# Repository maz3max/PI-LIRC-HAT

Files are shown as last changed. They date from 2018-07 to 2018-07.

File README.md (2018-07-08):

# Raspberry PI LIRC HAT #
## Now, you can control everything with an infrared remote with your Raspberry Pi! ##

This an extension PCB for Raspberry PIs with 40 Pins.

Its purpose is to provide a infrared interface compatible with [LIRC](http://www.lirc.org/).

I did my very best to fulfill the [Raspberry Pi HAT specification](https://github.com/raspberrypi/hats).

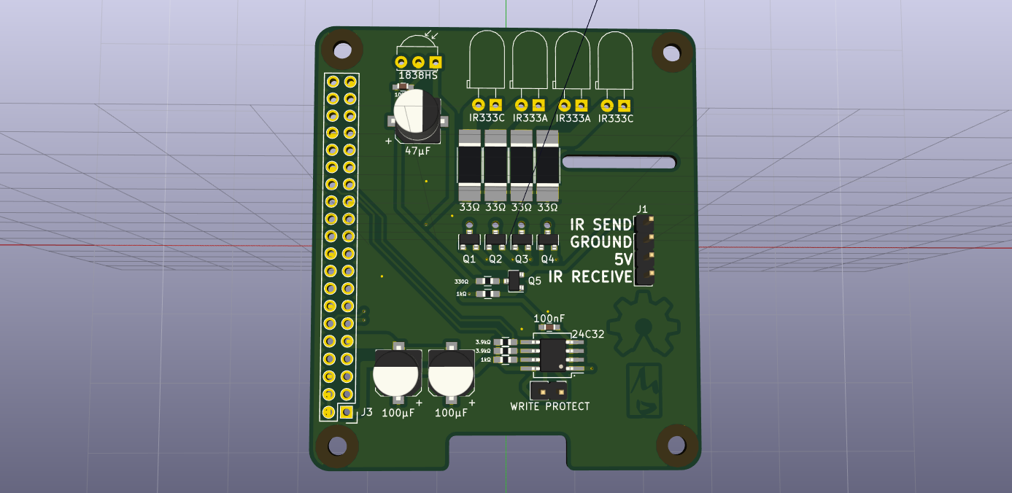
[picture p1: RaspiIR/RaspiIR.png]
3D render


To build it, you need:
* bravery, soldering skills, linux
* The PCB like in the design file in RaspiIR/RaspiIR.kicad_pcb
* 2x 100nF Ceramic Cap 0603 SMD
* 2x 100uF Electrolytic Cap SMD 6.3mm diameter
* 2x IR-LED: Everlight IR333-A
* 2x IR-LED: Everlight IR333C/H0/L10
* 1x TSOP383xx or AX-1838 IR receiver
* 5x MMBT3904TPMSCT-ND NPN transistor SOT-23
* 1x 24C32 I2C eeprom SOIC-8 or SO-8
* 4x 33R 1W 2512 SMD resistor
* 1x 330R 0603 SMD resistor
* 2x 1k 0603 SMD resistor
* 2x 3.9k 0603 SMD resistor
* 1x Pin-Header 0.1" pitch 2x20 pins (at least 8mm high)

After soldering it all together, you have to generate and write content on the ID eeprom. Its purpose is to load the driver when your Raspberry Pi boots.

To achieve this, follow these steps:

1. compile the tools in pi-lirc-hat/eepromutils with ```make```
2. use ```./eepmake eeprom_settings.txt lircHAT.eep lirc-rpi-overlay.dtbo -c setup-readme-blob``` to compile the eeprom content
3. connect the eeprom to the I2C-Pins of a Raspberry (NOT the ID-SCL, ID-SDA pins)
4. read on how to use eepflash with ```./eepflash.sh -h```
5. use eepflash to write the content to the ID eeprom, e.g.:```./eepflash.sh -w -f=lircHAT.eep -t=24c32 -d=1 -a=50```

After that, you have to install lirc on the Raspberry. This is documented in pi-lirc-hat/eepromutils/setup-readme-blob.

You can also find this in /proc/device-tree/hat/custom_0, because it is included in the eeprom! :D

The design with the 4 IR leds is inspired by [TV-B-Gone](https://learn.adafruit.com/tv-b-gone-kit/overview). The driver overlay is from the [Raspberry Pi Kernel source tree](https://github.com/raspberrypi/linux) with slight modifications. The PCB was designed using [KiCAD](http://kicad-pcb.org/). I used a template for the PCB design which can be found [here](https://github.com/xesscorp/RPi_Hat_Template)

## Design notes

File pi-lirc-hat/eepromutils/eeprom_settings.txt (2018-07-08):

########################################################################
# EEPROM settings text file
#
# Edit this file for your particular board and run through eepmake tool,
# then use eepflash tool to write to attached HAT ID EEPROM 
#
# Tools available:
#  eepmake   Parses EEPROM text file and creates binary .eep file
#  eepdump   Dumps a binary .eep file as human readable text (for debug)
#  eepflash  Write or read .eep binary image to/from HAT EEPROM
#
########################################################################

########################################################################
# Vendor info

# 128 bit UUID. If left at zero eepmake tool will auto-generate
# RFC 4122 compliant UUID
product_uuid 00000000-0000-0000-0000-000000000000

# 16 bit product id
product_id 0x1337

# 16 bit product version
product_ver 0x0001

# ASCII vendor string  (max 255 characters)
vendor "maz3max"

# ASCII product string (max 255 characters)
product "Raspberry LIRC HAT"

########################################################################
# GPIO bank settings, set to nonzero to change from the default.
# NOTE these setting can only be set per BANK, uncommenting any of
# these will force the bank to use the custom setting.

# drive strength, 0=default, 1-8=2,4,6,8,10,12,14,16mA, 9-15=reserved
gpio_drive 0

# 0=default, 1=slew rate limiting, 2=no slew limiting, 3=reserved
gpio_slew 0

# 0=default, 1=hysteresis disabled, 2=hysteresis enabled, 3=reserved
gpio_hysteresis 0

# If board back-powers Pi via 5V GPIO header pins:
# 0 = board does not back-power
# 1 = board back-powers and can supply the Pi with a minimum of 1.3A
# 2 = board back-powers and can supply the Pi with a minimum of 2A
# 3 = reserved
# If back_power=2 then USB high current mode will be automatically 
# enabled on the Pi
back_power 0

########################################################################
# GPIO pins, uncomment for GPIOs used on board
# Options for FUNCTION: INPUT, OUTPUT, ALT0-ALT5
# Options for PULL: DEFAULT, UP, DOWN, NONE
# NB GPIO0 and GPIO1 are reserved for ID EEPROM so cannot be set

#         GPIO  FUNCTION  PULL
#         ----  --------  ----
#setgpio  2     INPUT     DEFAULT
#setgpio  3     INPUT     DEFAULT
#setgpio  4     INPUT     DEFAULT
#setgpio  5     INPUT     DEFAULT
#setgpio  6     INPUT     DEFAULT
#setgpio  7     INPUT     DEFAULT
#setgpio  8     INPUT     DEFAULT
#setgpio  9     INPUT     DEFAULT
#setgpio  10    INPUT     DEFAULT
#setgpio  11    INPUT     DEFAULT
#setgpio  12    INPUT     DEFAULT
#setgpio  13    INPUT     DEFAULT
#setgpio  14    INPUT     DEFAULT
#setgpio  15    INPUT     DEFAULT
#setgpio  16    INPUT     DEFAULT
setgpio  17    OUTPUT    DEFAULT
setgpio  18    INPUT     DEFAULT
#setgpio  19    INPUT     DEFAULT
#setgpio  20    INPUT     DEFAULT
#setgpio  21    INPUT     DEFAULT
#setgpio  22    INPUT     DEFAULT
#setgpio  23    INPUT     DEFAULT
#setgpio  24    INPUT     DEFAULT
#setgpio  25    INPUT     DEFAULT
#setgpio  26    INPUT     DEFAULT
#setgpio  27    INPUT     DEFAULT

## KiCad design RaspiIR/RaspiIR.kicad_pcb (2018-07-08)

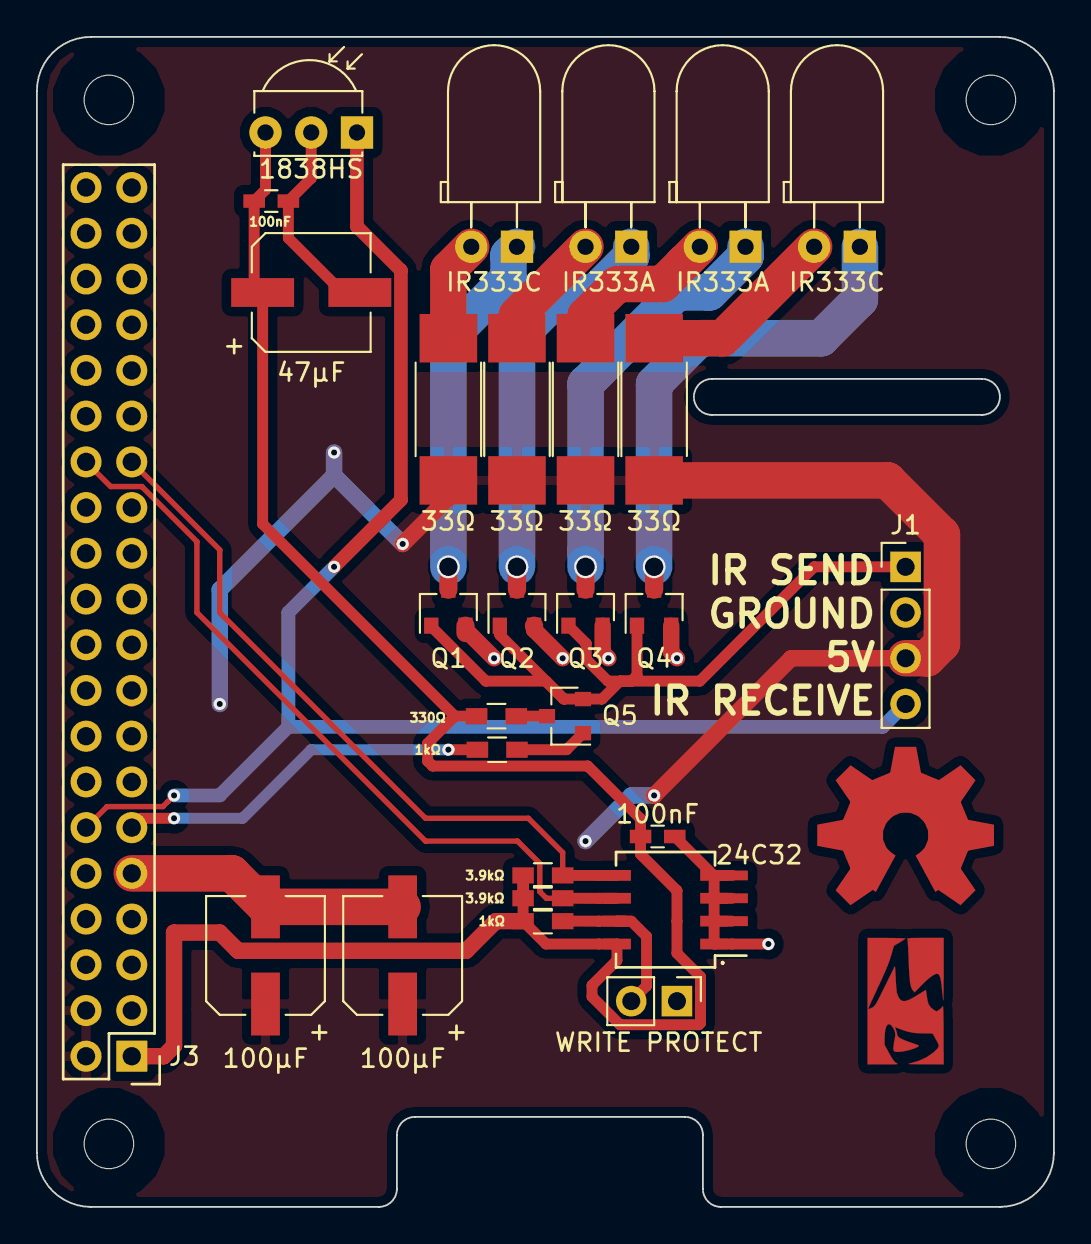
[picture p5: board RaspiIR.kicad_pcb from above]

Board: 2 copper layers, 56.5 x 65.0 mm, 30 parts (0 on the bottom side), 19 nets.

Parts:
1kΩ, 1kΩ#2: 1k; R_0603_HandSoldering
3.9kΩ, 3.9kΩ#2: 3k9; R_0603_HandSoldering
24C32: CAT24C32WI-GT3; SOIC-8_3.9x4.9mm_Pitch1.27mm
33Ω, 33Ω#2, 33Ω#3, 33Ω#4: 33; R_2512_HandSoldering
47µF, 100µF, 100µF#2: 100u; CP_Elec_6.3x7.7
100nF, 100nF#2: 100n; C_0603_HandSoldering
330Ω: 330; R_0603_HandSoldering
1838HS: TSOP343xx; IRReceiver_Vishay_MOLD-3pin
.: SO-8_5.3x6.2mm_Pitch1.27mm
IR333A, IR333A#2, IR333C, IR333C#2: LED; LED_D5.0mm_Horicontal_O2.54mm
J1: Conn_01x04_Male; Pin_Header_Straight_1x04_Pitch2.54mm
J3: Raspberry_Pi_2_3; Pin_Header_Straight_2x20
OSHW_COPPER_10MM: VAL**; OSHW_COPPER_10MM
Q1, Q2, Q3, Q4, Q5: MMBT3904; SOT-23
WRITE PROTECT: Conn_01x02; Pin_Header_Straight_1x02_Pitch2.54mm

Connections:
+3V3: 1kΩ#2.1, 3.9kΩ.1, 3.9kΩ#2.1, 24C32.8, 47µF.1, 100nF.1, 100nF#2.1, 330Ω.1, 1838HS.3, ..8, J3.1
+5V: 33Ω.2, 33Ω#2.2, 33Ω#3.2, 33Ω#4.2, 100µF.1, 100µF#2.1, J1.3, J3.2, J3.4
GND: 24C32.1, 24C32.2, 24C32.3, 24C32.4, 47µF.2, 100nF.2, 100nF#2.2, 100µF.2, 100µF#2.2, 1838HS.2, ..1, ..2, ..3, ..4, J1.2, J3.6, J3.9, J3.14, J3.20, J3.25, J3.30, J3.34, J3.39, Q1.2, Q2.2, Q3.2, Q4.2, WRITE PROTECT.1
ID_SCL: 3.9kΩ#2.2, 24C32.6, ..6, J3.28
ID_SDA: 3.9kΩ.2, 24C32.5, ..5, J3.27
IR_RECV: 1838HS.1, J1.4, J3.12
IR_SEND: J1.1, Q1.1, Q2.1, Q3.1, Q4.1, Q5.2
IR_SEND_IO: 1kΩ.2, J3.11
unnamed: IR333C.1, Q1.3
unnamed: 33Ω.1, IR333C.2
unnamed: IR333A.1, Q2.3
unnamed: 33Ω#2.1, IR333A.2
unnamed: IR333A#2.1, Q3.3
unnamed: 33Ω#3.1, IR333A#2.2
unnamed: IR333C#2.1, Q4.3
unnamed: 33Ω#4.1, IR333C#2.2
unnamed: 1kΩ#2.2, 24C32.7, ..7, WRITE PROTECT.2
unnamed: 1kΩ.1, Q5.1
unnamed: 330Ω.2, Q5.3

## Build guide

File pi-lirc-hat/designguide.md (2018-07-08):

# ADD-ON BOARD / HAT DESIGN GUIDE
---

## GPIO Pins

**NOTE** All references to GPIO numbers within this document are referring to the BCM283x GPIOs (**NOT** pin numbers on the GPIO header).

## GPIO Configuration Sequencing

The default state for all Bank 0 pins will be inputs with either a pull up or pull down. The default pull state can be found in the [BCM2835 peripherals specificaion](http://www.raspberrypi.org/documentation/hardware/raspberrypi/bcm2835/BCM2835-ARM-Peripherals.pdf) section 6.2 table 6-31 (see the "Pull" column). It will require positive software configuration to change the state of these pins.

The one exception to this rule is ID_SC and ID_SD. GPIO0 (ID\_SD) and GPIO1 (ID\_SC) will be switched to ALT0 (I2C-0) mode and probed for an EEPROM at boot time. These pins will revert to inputs once the probe sequence has completed.

### Videocore GPIO setup

**As of 11/03/15, this section has been (largely) implemented in firmware. Only the gpio_hysteresis, gpio_slew and back_power are currently unsupported. **

At a very early point in the boot process, either GPIOMAN (for recent firmware) or the Videocore platform code sets the initial state of GPIO pins.

Note: For legacy platform code, several defaults were hardcoded. A Pi with old firmware (firmware older than the model release date) will often assume that it is a Pi 1 Model B and as such up to three output pins may be driven as outputs on boot. See the following section for the GPIOs that may be driven as output by default and the recommended method of designing hardware to guard against this.

After the GPIOMAN/platform code stage the VC bootloader will attempt to probe for an EEPROM attached to GPIO0 and GPIO1. If successful, a GPIO setup map (as described in the EEPROM data format) will be applied to Bank 0 pins. 

Note: For newer firmware, a config.txt option exists to enable the UART on GPIO14/GPIO15 prior to booting the ARM. The EEPROM probe routine will override this behaviour if an EEPROM is found.

**At this point the ARM is booted.** Linux now has notional exclusive control over the settings for Bank 0 pins (except GPIO0 ALT0 and GPIO1 ALT0) from this point onward.

### GPIO Requirements

GPIO pins ID_SC and ID_SD (GPIO0 and GPIO1) are reserved for use solely for board detection / identification. **The only allowed connections to the ID_ pins are an ID EEPROM plus 3.9K pull up resistors. Do not connect anything else to these pins!**

Raspberry Pi models A and B use some bank 0 GPIOs for board control functions and UART output:

    GPIO6 -> LAN_RUN
    GPIO14 -> UART_TX
    GPIO16 -> STATUS_LED

**If a user boots a Pi with legacy firmware these pins may get driven so an add-on board must avoid driving these, or use a current limiting resistor (or some other protection) if that is not possible. Note also that a board must not rely on the pull state of these pins during boot**

## ID EEPROM

Within the set of pins available on the GPIO header, ID_SC and ID_SD (GPIO0/SCL and GPIO1/SDA) are reserved for board detection / identification. **The only allowed connections to the ID_ pins are an ID EEPROM plus 3.9K pull up resistors. Do not connect anything else to these pins!**

The ID EEPROM is interrogated at boot time and provides the Pi with the vendor information, the required GPIO setup (pin settings and functions) for the board as well as a binary Linux device tree fragment which also specifies which hardware is used and therefore which drivers need loading. EEPROM information is also available to userland Linux software for identifying attached boards (probably via a sysfs interface but this is TBD).

Pull-ups must be provided on the top board for ID_SC and ID_SD (SCL and SDA respectively) to 3V3 if using an EEPROM. The required pull-up value is 3.9K.

**EEPROM Device Specification**

- 24Cxx type 3.3V I2C EEPROM must be used (some types are 5V only, do not use these).
- The EEPROM must be of the **16-bit** addressable type (**do not use ones with 8-bit addressing**)
- Do not use 'paged' type EEPROMs where the I2C lower address bit(s) select the EEPROM page.
- Only required to support 100kHz I2C mode.
- Devices that perform I2C clock stretching are not supported.
- Write protect pin must be supported and protect the entire device memory.

Note that due to the restrictions above (only using non-paged 16-bit addressable devices is allowed), many of the smaller I2C EEPROMs are ruled out - please check datasheets carefully when choosing a suitable EEPROM for your HAT.

A recommended part that satisfies the above constraints is OnSemi CAT24C32 which is a 32kbit (4kbyte) device. The minimum EEPROM size required is variable and depends on the size of the vendor data strings in the EEPROM and whether a device tree data blob is included (and its size) and whether any other vendor specific data is included.

It is recommended that EEPROM WP (write protect) pin be connected to a test point on the board and pulled up to 3V3 with a 1K resistor. The idea is that at board test/probe the EEPROM can be written (WP pin can be driven LOW), but there is no danger of a user accidentally changing the device contents once the board leaves the factory. Note that the recommended device has an internal pull down hence the stiff (1K) pull up is required. Note that on some devices WP does not write protect the entire array (e.g. some Microchip variants) – avoid using these.

It may be desirable for a board to have the ability for its EEPROM to be reflashed by an end user, in this case it is recommended to also include a user settable jumper to short WP to GND and make the EEPROM writable once more. At least this way a user has to perform a specific action to make the EEPROM writeable again before being able to re-flash it and a suitable warning process can be put in place to make sure the correct image is used.

Address pins where present on a device should be set to make sure the EEPROM I2C address is 0x50. This usually means tying them all to zero. (NB reduced pin count variants of the recommended device – e.g. SOT23-5 package - usually have A[2:0] set to 0 anyway).

Details of the EEPROM data format can be found in the [EEPROM format specification](eeprom-format.md). [Software tools](./eepromutils) are available for creation of valid EEPROM images, to flash an image or read and dump and image to/from an attached ID EEPROM.

[The following schematic fragment](eeprom-circuit.png) is an example of connecting an EEPROM  including a jumper and probe point to disable write protect.

## Mechanical Specification

The [following drawing](hat-board-mechanical.pdf) gives the mechanical details for add-on boards which conform to the HAT specification.

## Back Powering the Pi via the GPIO Header

It is possible to power the Pi by supplying 5V through the GPIO header pins 2,4 and GND. The acceptable input voltage range is 5V ±5%.

Raspberry Pi Model A+, B+, Raspberry Pi 2B and 3B have an 'ideal' reverse current blocking diode (ZVD) circuit on their 5V input. The 5V GPIO header pins connect to the 5V net after the micro-USB input, polyfuse and input 'ideal' diode [made up of the PFET and matched PNP transistors](zvd-circuit.png). The ideal diode stops any appreciable current flowing back out of the 5V micro USB should the 5V net on the board be at a higher voltage than the 5V micro USB input.

If the add-on board uses any more GPIO connector pins than the first 26 and provides back-powering via the 5V GPIO header pins it is required to:

1. Implement a duplicate power safety diode before the HAT 5V net (which then feeds power back through the 5V GPIO pins) as shown in [this diagram](backpowering-diagram.png). Alternatively provide some other mechanism to guarantee that it is safe if both the Pi PSU and add-on board PSU are connected. It is still recommended to add this circuitry for new board designs that only implement the first 26 pins of the GPIO header but that also implement back powering (see below note)
2. Make sure that the supply that does the back-powering can supply 5V at 2.5A.

NOTE that the Raspberry Pi 3B+ and Pi Zero and ZeroW **do not** include an input ZVD. The micro-USB input on a Pi is expected to / almost universally is driven by a power source which does not sink current, i.e. it will not try to actively pull down a voltage higher than its regulated voltage. If a HAT back-powers a Pi and uses a power source that does not try to sink current (and will safely stop/pause regulation if its input voltage is higher than its regulation voltage) it is OK to not include a ZVD on a HAT. If you are unsure or don't know then please include the ZVD! The HAT designer is responsible for the safety of their product.

**Under no circumstances should a power source be connected to the GPIO header 3.3V pins.**

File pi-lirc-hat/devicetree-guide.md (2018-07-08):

# HAT Devicetree Blob guide

###**This section is under active development and portions of the guide rely on software features not yet implemented.**
---
Within the HAT specification is the requirement to include a data atom that contains a devicetree overlay binary (`.dtbo` or `-overlay.dtb`).

First, read and understand what a device tree is and how it is used by system software (i.e. Linux).

[Device Tree Usage](http://elinux.org/Device_Tree_Usage)

[Device Tree For Dummies](http://events.linuxfoundation.org/sites/events/files/slides/petazzoni-device-tree-dummies.pdf)

An extension to this mechanism of hardware description is the introduction of an overlay: a partially-complete devicetree fragment that "joins up" to a higher-level device tree. The basic idea is that this overlay will be read on boot (by the VC bootloader), parsed and merged into the system-level device tree passed through to the ARM running Linux.

The purpose of this overlay is that it allows true automatic configuration of all devices attached to the HAT, as long as there are Linux device drivers available for the hardware in question. 

The devicetree overlay will be of particular use to add-on board designers making use of the I2C-1, SPI and I2S buses that require chip selects / addresses to be specified in order to be probed and set up correctly by the respective Linux device driver, but it will also allow simple devices such as LEDs and buttons to be recognised by Linux and connected up to e.g. the kernel input events subsystem.

The process of writing an overlay is outside the scope of this document. Readers are instead referred to this Raspberry Pi document:

[Device Trees, Overlays and Parameters](http://www.raspberrypi.org/documentation/configuration/device-tree.md)

### HAT identification

To avoid the need for modules and applications to access the EEPROM, the VC bootloader reads the vendor, product and custom data and populates the `/hat` node of the device tree. This can be read by kernel modules using the standard DT API (`of_*`), or via `/proc/device-tree/hat` from user-space. Here is an example of the sort of information you will find there:
```
/proc/device-tree/hat/vendor:
ACME Corp.

/proc/device-tree/hat/product:
Dunce HAT

/proc/device-tree/hat/product_id:
0x0001

/proc/device-tree/hat/product_ver:
0x0001

/proc/device-tree/hat/uuid:
c617cf6a-7de5-4948-0000-000001b86eb0

/proc/device-tree/hat/custom_0:
The boy stood on the burning deck
His lips were all a-quiver.

/proc/device-tree/hat/custom_1:
Lorem ipsum dolor sit amet, consectetur adipiscing elit, sed do eiusmod tempor incididunt ut labore et dolore magna aliqua.
```
The custom blobs are copied verbatim, and may contain arbitrary binary data.

It is permissible for the overlay to supplement this data with additional information, but the standard properties always take precedence, overwriting any user-supplied values. Conversely, if there is no HAT present then the `/hat` node is deleted just before boot.

### Pinctrl nodes vs GPIO map

Within the devicetree fragment is scope for adding pinctrl nodes that alter the setup of GPIO pins. The timing or sequencing used by pinctrl for GPIO setup may be non-trivial: for example a GPIO could be nominated as a reset pin for an external MCU that may require a reset pulse of a certain length, or a GPIO could be nominated to enable an external power chain that requires a certain period of stabilisation before attempting to talk to any attached devices. The Linux Pinctrl subsystem is designed to cater for complex requirements such as these.

The GPIO pin data map in the EEPROM is **still required** even if pinctrl configuration nodes are specified in the device tree blob. The GPIO map is parsed by the Videocore bootloader prior to ARM boot and **not** Linux.

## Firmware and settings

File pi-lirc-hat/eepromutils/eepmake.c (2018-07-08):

/*
 *	Parses EEPROM text file and createds binary .eep file
 *	Usage: eepmake input_file output_file
*/

#include <stdio.h>
#include <stdlib.h>
#include <ctype.h>
#include <string.h>
#include <stdbool.h>
#include <unistd.h>
#include <fcntl.h>

#include "eeptypes.h"

#define HEADER_SIGN 0x69502d52 //"R-Pi" in ASCII reversed for endianness

//todo: larger initial mallocs

struct header_t header;
struct atom_t *custom_atom, vinf_atom, gpio_atom, dt_atom;
struct vendor_info_d* vinf;
struct gpio_map_d* gpiomap;

bool product_serial_set, product_id_set, product_ver_set, vendor_set, product_set, 
			gpio_drive_set, gpio_slew_set, gpio_hysteresis_set, gpio_power_set;
			
bool data_receive, has_dt, receive_dt;
			
char **data;
char *current_atom; //rearranged to write out
unsigned int data_len, custom_ct, total_size, data_cap, custom_cap;


int write_binary(char* out) {
	FILE *fp;
	int i, offset;
	short crc;
	
	fp=fopen(out, "wb");
	if (!fp) {
		printf("Error writing file %s\n", out);
		return -1;
	}
	
	fwrite(&header, sizeof(header), 1, fp);
		
		
	current_atom = (char *) malloc(vinf_atom.dlen+ATOM_SIZE-CRC_SIZE);
	offset = 0;
	//vendor information atom first part
	memcpy(current_atom, &vinf_atom, ATOM_SIZE-CRC_SIZE);
	offset += ATOM_SIZE-2;
	//data first part
	memcpy(current_atom+offset, vinf_atom.data, VENDOR_SIZE);
	offset += VENDOR_SIZE;	
	//data strings
	memcpy(current_atom+offset, vinf->vstr, vinf->vslen);
	offset += vinf->vslen;
	memcpy(current_atom+offset, vinf->pstr, vinf->pslen);
	offset += vinf->pslen;
	//vinf last part
	crc = getcrc(current_atom, offset);
	memcpy(current_atom+offset, &crc, CRC_SIZE);
	offset += CRC_SIZE;
	
	fwrite(current_atom, offset, 1, fp);
	free(current_atom);
	
	current_atom = (char *) malloc(gpio_atom.dlen+ATOM_SIZE-CRC_SIZE);
	offset = 0;
	//GPIO map first part
	memcpy(current_atom, &gpio_atom, ATOM_SIZE-CRC_SIZE);
	offset += ATOM_SIZE-CRC_SIZE;
	//GPIO data
	memcpy(current_atom+offset, gpiomap, GPIO_SIZE);
	offset += GPIO_SIZE;
	//GPIO map last part
	crc = getcrc(current_atom, offset);
	memcpy(current_atom+offset, &crc, CRC_SIZE);
	offset += CRC_SIZE;
	
	fwrite(current_atom, offset, 1, fp);
	free(current_atom);
	
	if (has_dt) {
		printf("Writing out DT...\n");
		current_atom = (char *) malloc(dt_atom.dlen+ATOM_SIZE-CRC_SIZE);
		offset = 0;
		
		memcpy(current_atom, &dt_atom, ATOM_SIZE-CRC_SIZE);
		offset += ATOM_SIZE-CRC_SIZE;
		
		memcpy(current_atom+offset, dt_atom.data, dt_atom.dlen-CRC_SIZE);
		offset += dt_atom.dlen-CRC_SIZE;
		
		crc = getcrc(current_atom, offset);
		memcpy(current_atom+offset, &crc, CRC_SIZE);
		offset += CRC_SIZE;
		
		fwrite(current_atom, offset, 1, fp);
		free(current_atom);
	}
	
	for (i = 0; i<custom_ct; i++) {
		custom_atom[i].count-=!has_dt;
		
		current_atom = (char *) malloc(custom_atom[i].dlen+ATOM_SIZE-CRC_SIZE);
		offset = 0;
		
		memcpy(current_atom, &custom_atom[i], ATOM_SIZE-CRC_SIZE);
		offset += ATOM_SIZE-CRC_SIZE;
		
		memcpy(current_atom+offset, custom_atom[i].data, custom_atom[i].dlen-CRC_SIZE);
		offset += custom_atom[i].dlen-CRC_SIZE;
		
		crc = getcrc(current_atom, offset);
		memcpy(current_atom+offset, &crc, CRC_SIZE);
		offset += CRC_SIZE;
		
		fwrite(current_atom, offset, 1, fp);
		free(current_atom);
	}
	
	
	fflush(fp);
	fclose(fp);
	return 0;
}


void parse_data(char* c) {
	int k;
	char s;
	char* i = c;
	char* j = c;
	while(*j != '\0')
	{
		*i = *j++;
		if(isxdigit(*i))
			i++;
	}
	*i = '\0';
	
	int len = strlen(c);
	if (len % 2 != 0) {
		printf("Error: data must have an even number of hex digits\n");
	} else {
		for (k = 0; k<len/2; k++) {
			//read a byte at a time
			s = *(c+2);
			*(c+2)='\0';
			
			if (data_len==data_cap) {
				data_cap *=2;
				*data = (char *) realloc(*data, data_cap);
			}
			
			sscanf(c, "%2x", *data+data_len++);
			
			*(c+2) = s;
			c+=2;
		}
	}
}


void finish_data() {
	if (data_receive) {
		*data = (char *) realloc(*data, data_len);
			
		total_size+=ATOM_SIZE+data_len;

		if (receive_dt) {
			dt_atom.type = ATOM_DT_TYPE;
			dt_atom.count = ATOM_DT_NUM;
			dt_atom.dlen = data_len+CRC_SIZE;
		} else {
			//finish atom description
			custom_atom[custom_ct].type = ATOM_CUSTOM_TYPE;
			custom_atom[custom_ct].count = 3+custom_ct;
			custom_atom[custom_ct].dlen = data_len+CRC_SIZE;
			
			custom_ct++;
		}
	}
}


void parse_command(char* cmd, char* c) {
	int val;
	uint32_t high1, high2;
	char *fn, *pull;
	char pin;
	bool valid;
	bool continue_data=false;
	
	/* Vendor info related part */
	if (strcmp(cmd, "product_uuid")==0) {
		product_serial_set = true; //required field
		high1 = 0; high2 = 0;
		
		sscanf(c, "%100s %08x-%04x-%04x-%04x-%04x%08x\n", cmd, &vinf->serial_4, 
			&high1, &vinf->serial_3, &high2, &vinf->serial_2, &vinf->serial_1);
		
		vinf->serial_3 |= high1<<16;
		vinf->serial_2 |= high2<<16;
		
		if ((vinf->serial_4==0) && (vinf->serial_3==0) && (vinf->serial_2==0) && (vinf->serial_1==0)) {
			//read 128 random bits from /dev/urandom
			int random_file = open("/dev/urandom", O_RDONLY);
			ssize_t result = read(random_file, &vinf->serial_1, 16);
			close(random_file);
			if (result <= 0) printf("Unable to read from /dev/urandom to set up UUID");
			else {
				//put in the version
				vinf->serial_3 = (vinf->serial_3 & 0xffff0fff) | 0x00004000;
				
				//put in the variant
				vinf->serial_2 = (vinf->serial_2 & 0x3fffffff) | 0x80000000;
				
				printf("UUID=%08x-%04x-%04x-%04x-%04x%08x\n", vinf->serial_4, vinf->serial_3>>16, vinf->serial_3 & 0xffff, vinf->serial_2>>16, vinf->serial_2 & 0xffff, vinf->serial_1);
			}
 
		}
		
	} else if (strcmp(cmd, "product_id")==0) {
		product_id_set = true; //required field
		sscanf(c, "%100s %hx", cmd, &vinf->pid);
		
	} else if (strcmp(cmd, "product_ver")==0) {
		product_ver_set = true; //required field
		sscanf(c, "%100s %hx", cmd, &vinf->pver);
		
	} else if (strcmp(cmd, "vendor")==0) {
		vendor_set = true; //required field
		
		vinf->vstr = (char*) malloc (256);
		sscanf(c, "%100s \"%255[^\"]\"", cmd, vinf->vstr);
		
		total_size-=vinf->vslen;
		vinf_atom.dlen-=vinf->vslen;
		
		vinf->vslen = strlen(vinf->vstr);
		
		total_size+=vinf->vslen;
		vinf_atom.dlen+=vinf->vslen;
		
	} else if (strcmp(cmd, "product")==0) {
		product_set = true; //required field
		
		vinf->pstr = (char*) malloc (256);
		sscanf(c, "%100s \"%255[^\"]\"", cmd, vinf->pstr);
		
		total_size-=vinf->pslen;
		vinf_atom.dlen-=vinf->pslen;
		
		vinf->pslen = strlen(vinf->pstr);
		
		total_size+=vinf->pslen;
		vinf_atom.dlen+=vinf->pslen;
	} 
	
	/* GPIO map related part */
	else if (strcmp(cmd, "gpio_drive")==0) {
		gpio_drive_set = true; //required field
		
		sscanf(c, "%100s %1x", cmd, &val);
		if (val>8 || val<0) printf("Warning: gpio_drive property in invalid region, using default value instead\n");
		else gpiomap->flags |= val;
		
		
	} else if (strcmp(cmd, "gpio_slew")==0) {
		gpio_slew_set = true; //required field
		
		sscanf(c, "%100s %1x", cmd, &val);
		
		if (val>2 || val<0) printf("Warning: gpio_slew property in invalid region, using default value instead\n");
		else gpiomap->flags |= val<<4;
		
	} else if (strcmp(cmd, "gpio_hysteresis")==0) {
		gpio_hysteresis_set = true; //required field
		
		sscanf(c, "%100s %1x", cmd, &val);
		
		if (val>2 || val<0) printf("Warning: gpio_hysteresis property in invalid region, using default value instead\n");
		else gpiomap->flags |= val<<6;
		
	} else if (strcmp(cmd, "back_power")==0) {
		gpio_power_set = true; //required field
		
		sscanf(c, "%100s %1x", cmd, &val);
		
		if (val>2 || val<0) printf("Warning: back_power property in invalid region, using default value instead\n");
		else gpiomap->power = val;
		
	} else if (strcmp(cmd, "setgpio")==0) {
		fn = (char*) malloc (101);
		pull = (char*) malloc (101);
		
		sscanf(c, "%100s %d %100s %100s", cmd, &val, fn, pull);
		
		if (val<GPIO_MIN || val>=GPIO_COUNT) printf("Error: GPIO number out of bounds\n");
		else {
			valid = true;
			pin = 0;
			
			if (strcmp(fn, "INPUT")==0) {
				//no action
			} else if (strcmp(fn, "OUTPUT")==0) {
				pin |= 1;
			} else if (strcmp(fn, "ALT0")==0) {
				pin |= 4;
			} else if (strcmp(fn, "ALT1")==0) {
				pin |= 5;
			} else if (strcmp(fn, "ALT2")==0) {
				pin |= 6;
			} else if (strcmp(fn, "ALT3")==0) {
				pin |= 7;
			} else if (strcmp(fn, "ALT4")==0) {
				pin |= 3;
			} else if (strcmp(fn, "ALT5")==0) {
				pin |= 2;
			} else {
				printf("Error at setgpio: function type not recognised\n");
				valid=false;
			}
			
			if (strcmp(pull, "DEFAULT")==0) {
				//no action
			} else if (strcmp(pull, "UP")==0) {
				pin |= 1<<5;
			} else if (strcmp(pull, "DOWN")==0) {
				pin |= 2<<5;
			} else if (strcmp(pull, "NONE")==0) {
				pin |= 3<<5;
			} else {
				printf("Error at setgpio: pull type not recognised\n");
				valid=false;
			}
			
			pin |= 1<<7; //board uses this pin
			
			if (valid) gpiomap->pins[val] = pin;
		}
	} 
	
	/* DT atom related part */
	else if (strcmp(cmd, "dt_blob")==0) {
		finish_data();
		
		has_dt = true;
		c+=strlen("dt_blob");
		
		receive_dt=true;
		data_receive=true;
		
		data_len = 0;
		data_cap = 4;
		data = &dt_atom.data;
		*data = (char *) malloc(data_cap);
		
		parse_data(c);
		continue_data = true;
	
	} 
	
	/* Custom data related part */
	else if (strcmp(cmd, "custom_data")==0) {
		finish_data();
		
		c+=strlen("custom_data");
		
		if (custom_cap == custom_ct) {
			custom_cap *= 2;
			custom_atom = (struct atom_t*) realloc(custom_atom, custom_cap * sizeof(struct atom_t));
		}
		
		receive_dt=false;
		data_receive=true;
		
		data_len = 0;
		data_cap = 4;
		data = &custom_atom[custom_ct].data;
		*data = (char *) malloc(data_cap);
		
		parse_data(c);
		continue_data = true;
	
	} else if (strcmp(cmd, "end") ==0) {
		//close last data atom
		continue_data=false;
	}
	/* Incoming data */
	else if (data_receive) {
		parse_data(c);
		continue_data = true;
	} 
	
	
	if (!continue_data) finish_data();
	
}

int read_text(char* in) {
	FILE * fp;
	char * line = NULL;
	char * c = NULL;
	size_t len = 0;
	ssize_t read;
	char *comment = NULL;
	int atomct = 2;
	int linect = 0;
	char * command = (char*) malloc (101);
	int i;
	
	has_dt = false;
	
	printf("Opening file %s for read\n", in);
	
	fp = fopen(in, "r");
	if (fp == NULL) {
		printf("Error opening input file\n");
		return -1;
	}

	//allocating memory and setting up required atoms
	custom_cap = 1;
	custom_atom = (struct atom_t*) malloc(sizeof(struct atom_t) * custom_cap);
	
	total_size=ATOM_SIZE*2+HEADER_SIZE+VENDOR_SIZE+GPIO_SIZE;
	
	vinf_atom.type = ATOM_VENDOR_TYPE;
	vinf_atom.count = ATOM_VENDOR_NUM;
	vinf = (struct vendor_info_d *) calloc(1, sizeof(struct vendor_info_d));
	vinf_atom.data = (char *)vinf;
	vinf_atom.dlen = VENDOR_SIZE + CRC_SIZE;
	
	gpio_atom.type = ATOM_GPIO_TYPE;
	gpio_atom.count = ATOM_GPIO_NUM;
	gpiomap = (struct gpio_map_d *) calloc(1, sizeof(struct gpio_map_d));
	gpio_atom.data = (char *)gpiomap;
	gpio_atom.dlen = GPIO_SIZE + CRC_SIZE;
	
	while ((read = getline(&line, &len, fp)) != -1) {
		linect++;
		c = line;
		
		for (i=0; i<read; i++) if (c[i]=='#') c[i]='\0';
		
		while (isspace(*c)) ++c;
		
		
		if (*c=='\0' || *c=='\n' || *c=='\r') {
			//empty line, do nothing
		} else if (isalnum (*c)) {
			sscanf(c, "%100s", command);
			
#ifdef DEBUG
			printf("Processing line %u: %s", linect, c);
			if ((*(c+strlen(c)-1))!='\n') printf("\n");
#endif
			
			parse_command(command, c);
		
		
		} else printf("Can't parse line %u: %s", linect, c);
	}
	
	finish_data();
	
	if (!product_serial_set || !product_id_set || !product_ver_set || !vendor_set || !product_set || 
			!gpio_drive_set || !gpio_slew_set || !gpio_hysteresis_set || !gpio_power_set) {
			
		printf("Warning: required fields missing in vendor information or GPIO map, using default values\n");
	}
	
	printf("Done reading\n");
	
	return 0;
}


int read_dt(char* in) {
	FILE * fp;
	unsigned long size = 0;
	
	printf("Opening DT file %s for read\n", in);
	
	fp = fopen(in, "r");
	if (fp == NULL) {
		printf("Error opening input file\n");
		return -1;
	}
	
	fseek(fp, 0L, SEEK_END);
	size = ftell(fp);
	fseek(fp, 0L, SEEK_SET);
	
	printf("Adding %lu bytes of DT data\n", size);
	
	total_size+=ATOM_SIZE+size;
	has_dt = true;
	dt_atom.type = ATOM_DT_TYPE;
	dt_atom.count = ATOM_DT_NUM;
	dt_atom.dlen = size+CRC_SIZE;
	
	dt_atom.data = (char *) malloc(size);
	if (!fread(dt_atom.data, size, 1, fp)) goto err;
	
	
	fclose(fp);
	return 0;
	
err:
	printf("Unexpected EOF or error occurred\n");
	fclose(fp);
	return 0;
	
}

int read_custom(char* in) {
	FILE * fp;
	unsigned long size = 0;
	
	printf("Opening custom data file %s for read\n", in);
	
	fp = fopen(in, "r");
	if (fp == NULL) {
		printf("Error opening input file\n");
		return -1;
	}
	
	fseek(fp, 0L, SEEK_END);
	size = ftell(fp);
	fseek(fp, 0L, SEEK_SET);
	
	printf("Adding %lu bytes of custom data\n", size);
	
	total_size+=ATOM_SIZE+size;
	
	custom_atom[custom_ct].type = ATOM_CUSTOM_TYPE;
	custom_atom[custom_ct].count = 3+custom_ct;
	custom_atom[custom_ct].dlen = size+CRC_SIZE;
	
	custom_atom[custom_ct].data = (char *) malloc(size);
	if (!fread(custom_atom[custom_ct].data, size, 1, fp)) goto err;
	
	custom_ct++;
	
	fclose(fp);
	return 0;
	
err:
	printf("Unexpected EOF or error occurred\n");
	fclose(fp);
	return 0;
	
}
int main(int argc, char *argv[]) {
	int ret;
	int i, custom_o=0;
	
	if (argc<3) {
		printf("Wrong input format.\n");
		printf("Try 'eepmake input_file output_file [dt_file] [-c custom_file_1 ... custom_file_n]'\n");
		return 0;
	}
	
	
	ret = read_text(argv[1]);
	if (ret) {
		printf("Error reading and parsing input, aborting\n");
		return 0;
	}
	
	if (argc>3) {
		if (strcmp(argv[3], "-c")==0) {
			custom_o=4;
		} else {
			//DT file specified
			if (dt_atom.dlen) total_size-=(ATOM_SIZE +dt_atom.dlen - CRC_SIZE);
			ret = read_dt(argv[3]);
			if (ret) {
				printf("Error reading DT file, aborting\n");
				return 0;
			}
		}
	}
	
	if (argc>4 && strcmp(argv[4], "-c")==0) custom_o = 5;

	if (custom_o)
		for (i = custom_o; i<argc; i++) {
			//new custom data file
			ret = read_custom(argv[i]);
			if (ret) {
				printf("Error reading DT file, aborting\n");
				return 0;
			}
		}
	
	header.signature = HEADER_SIGN;
	header.ver = FORMAT_VERSION;
	header.res = 0;
	header.numatoms = 2+has_dt+custom_ct;
	header.eeplen = total_size;
	
	printf("Writing out...\n");
	
	ret = write_binary(argv[2]);
	if (ret) {
		printf("Error writing output\n");
		return 0;
	}
	
	printf("Done.\n");

	return 0;
}
